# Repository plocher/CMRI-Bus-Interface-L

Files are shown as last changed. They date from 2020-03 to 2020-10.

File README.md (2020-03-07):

# CMRI-Bus-Interface-L
## License: Creative Commons Attribution-NonCommercial-ShareAlike

RS422/485 driver for CMRI-Net - large 3" Tyco rail size

Adapter board for interfacing with CMRI Bus traffic using MRCS ‘duino example code. Uses an optional onboard 555 to generate TX/RX enable based on processor I/O direction

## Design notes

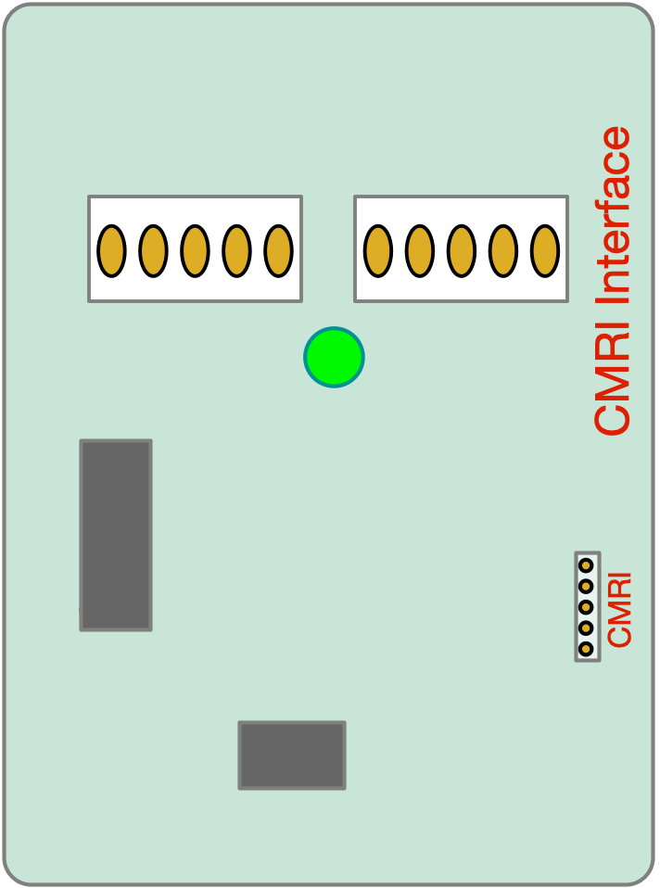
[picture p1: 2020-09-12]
CMRI-Bus-Interface-L-Graphic.png

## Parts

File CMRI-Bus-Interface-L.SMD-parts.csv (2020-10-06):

# name | smd? | value | package | component | x | y | Eagle-Angle | YX-Angle
C1 | SMD | 0.1uF | 0603-CAP | 0.1uf-0603-cap | 32.38 | 18.80 | 90.00 | -90.00
C2 | SMD | 0.01uF | 0603-CAP | 0.01uf-0603-cap | 29.21 | 10.16 | 270.00 | 90.00
C4 | SMD | 0.01uF | 0603-CAP | 0.01uf-0603-cap | 13.72 | 14.22 | 0.00 | 0.00
C5 | SMD | 0.01uF | 0603-CAP | 0.01uf-0603-cap | 19.43 | 10.16 | 270.00 | 90.00
D1 | SMD | BAV199 | SOT23 | bav199-sot23 | 15.24 | 10.16 | 90.00 | -90.00
R1-ALT | SMD | 12k | 0805-RES | 12k-0805-res | 32.51 | 10.16 | 270.00 | 90.00
R2 | SMD | 470 | 0805-RES | 470-0805-res | 38.10 | 45.09 | 90.00 | -90.00
TX | SMD | Y | 0603-LED | y-0603-led | 37.47 | 48.26 | 0.00 | 0.00
U1 | SMD | MAX3465CSD | SO14 | max3465csd-so14 | 13.97 | 20.32 | 90.00 | -90.00
U2 | SMD | NE555 | SO08 | ne555-so08 | 22.86 | 10.16 | 0.00 | 0.00

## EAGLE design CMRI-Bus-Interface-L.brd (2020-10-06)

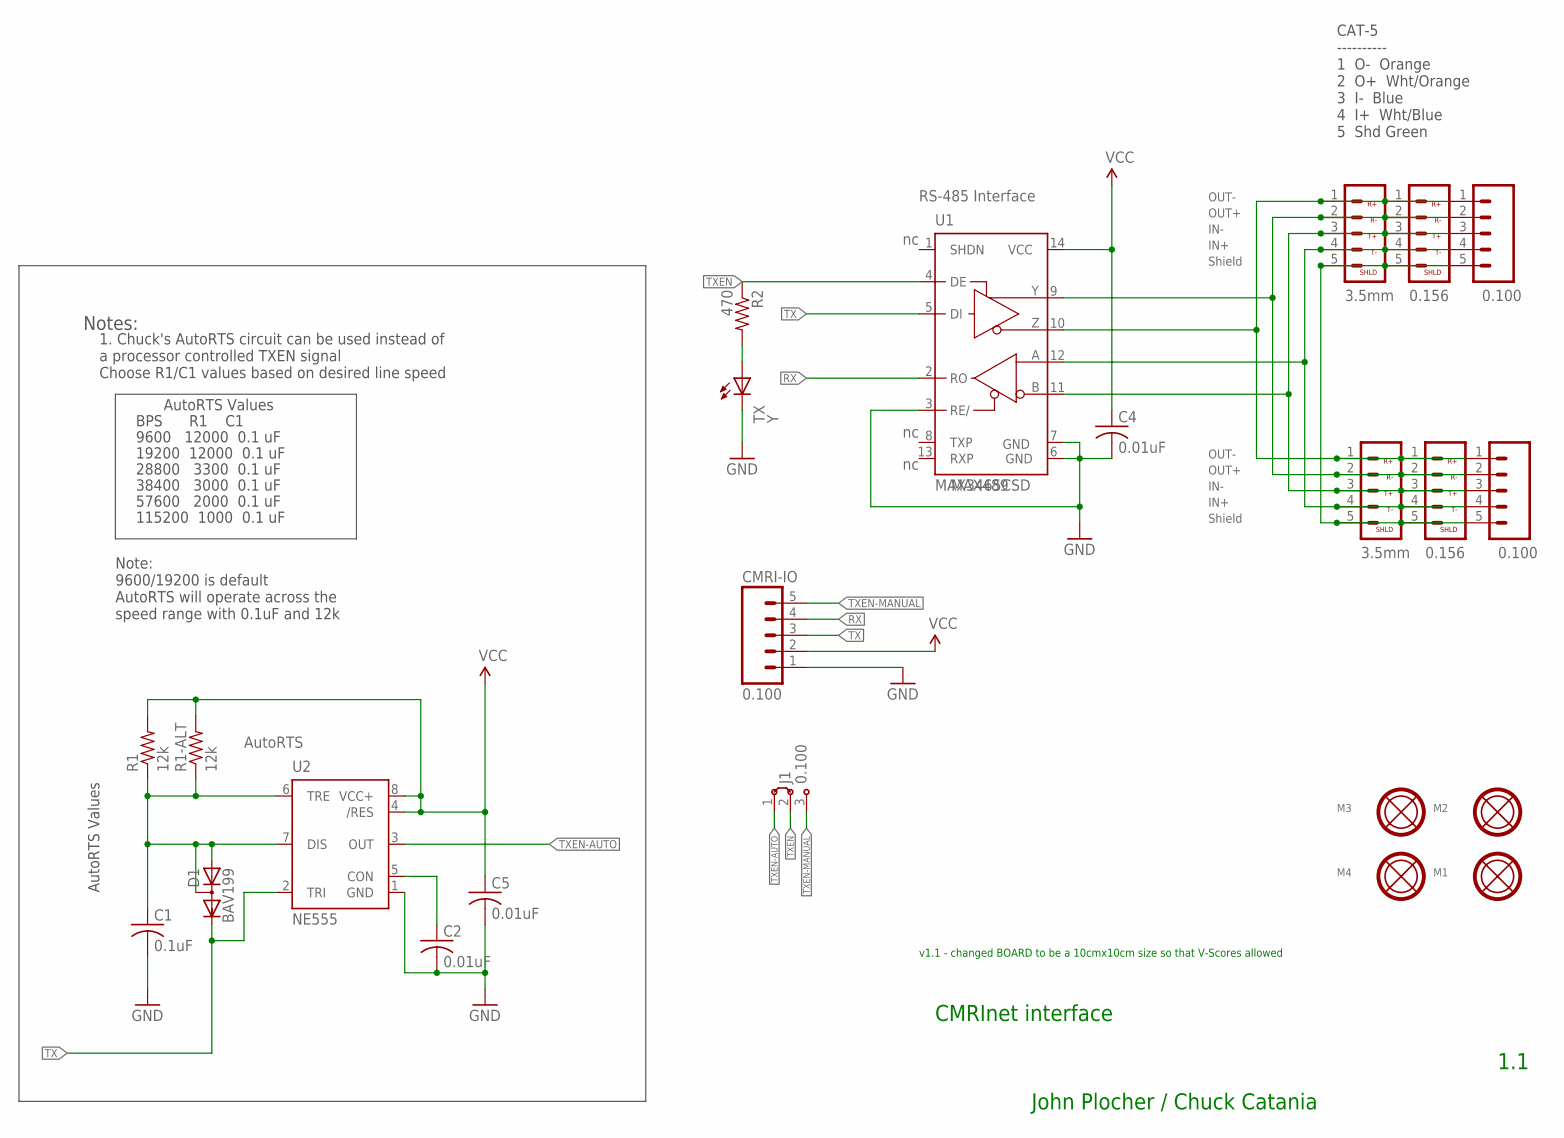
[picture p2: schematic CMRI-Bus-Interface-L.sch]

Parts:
C1: 0.1uF; 0603-CAP
C2, C4, C5: 0.01uF; 0603-CAP
CMRI-IO: 0.100; 1X05-CMRI-IO
CMRINET1, CMRINET2: 3.5mm; CMRINET-3.5MM
CMRINET3, CMRINET4: 0.156; KK-156-5
CON1, CON2: 0.100; 1X05_LOCK
D1: BAV199; SOT23
J1: 0.100; J3-254
M1, M2, M3, M4: MOUNTINGHOLE
R1: 12k; AXIAL-0.4-RES
R1-ALT: 12k; 0805-RES
R2: 470; 0805-RES
TX: Y; 0603-LED
U1: MAX3465CSD; SO14
U2: NE555; SO08

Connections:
GND: C1.2, C2.2, C4.2, C5.2, CMRI-IO.1, TX.C, U1.3 (RE/), U1.6 (GND), U1.7 (GND), U2.1 (GND)
IN+: CMRINET1.4, CMRINET2.4, CMRINET3.4, CMRINET4.4, CON1.4, CON2.4, U1.12 (A)
IN-: CMRINET1.3, CMRINET2.3, CMRINET3.3, CMRINET4.3, CON1.3, CON2.3, U1.11 (B)
unnamed: R2.2, TX.A
unnamed: C2.1, U2.5 (CON)
unnamed: C1.1, D1.1 (A), D1.3 (AC), R1.P$1 (1), R1-ALT.1, U2.6 (TRE), U2.7 (DIS)
OUT+: CMRINET1.2, CMRINET2.2, CMRINET3.2, CMRINET4.2, CON1.2, CON2.2, U1.9 (Y)
OUT-: CMRINET1.1, CMRINET2.1, CMRINET3.1, CMRINET4.1, CON1.1, CON2.1, U1.10 (Z)
RX: CMRI-IO.4, U1.2 (RO)
SHIELD: CMRINET1.5, CMRINET2.5, CMRINET3.5, CMRINET4.5, CON1.5, CON2.5
TX: CMRI-IO.3, D1.2 (C), U1.5 (DI), U2.2 (TRI)
TXEN: J1.2, R2.1, U1.4 (DE)
TXEN-AUTO: J1.1, U2.3 (OUT)
TXEN-MANUAL: CMRI-IO.5, J1.3
VCC: C4.1, C5.1, CMRI-IO.2, R1.P$2 (2), R1-ALT.2, U1.14 (VCC), U2.4 (/RES), U2.8 (VCC+)

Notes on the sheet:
MAX489
RS-485 Interface
Notes:
IN+
IN-
OUT+
OUT-
1. Chuck's AutoRTS circuit can be used instead of a processor controlled TXEN signal Choose R1/C1 values based on desired line speed
AutoRTS
AutoRTS Values
9600 12000 0.1 uF
19200 12000 0.1 uF
38400 3000 0.1 uF
57600 2000 0.1 uF
115200 1000 0.1 uF
BPS R1 C1
Shield
CAT-5 ---------- 1 O- Orange 2 O+ Wht/Orange 3 I- Blue 4 I+ Wht/Blue 5 Shd Green
28800 3300 0.1 uF
Note: 9600/19200 is default AutoRTS will operate across the speed range with 0.1uF and 12k
1.1
CMRInet interface
John Plocher / Chuck Catania
v1.1 - changed BOARD to be a 10cmx10cm size so that V-Scores allowed

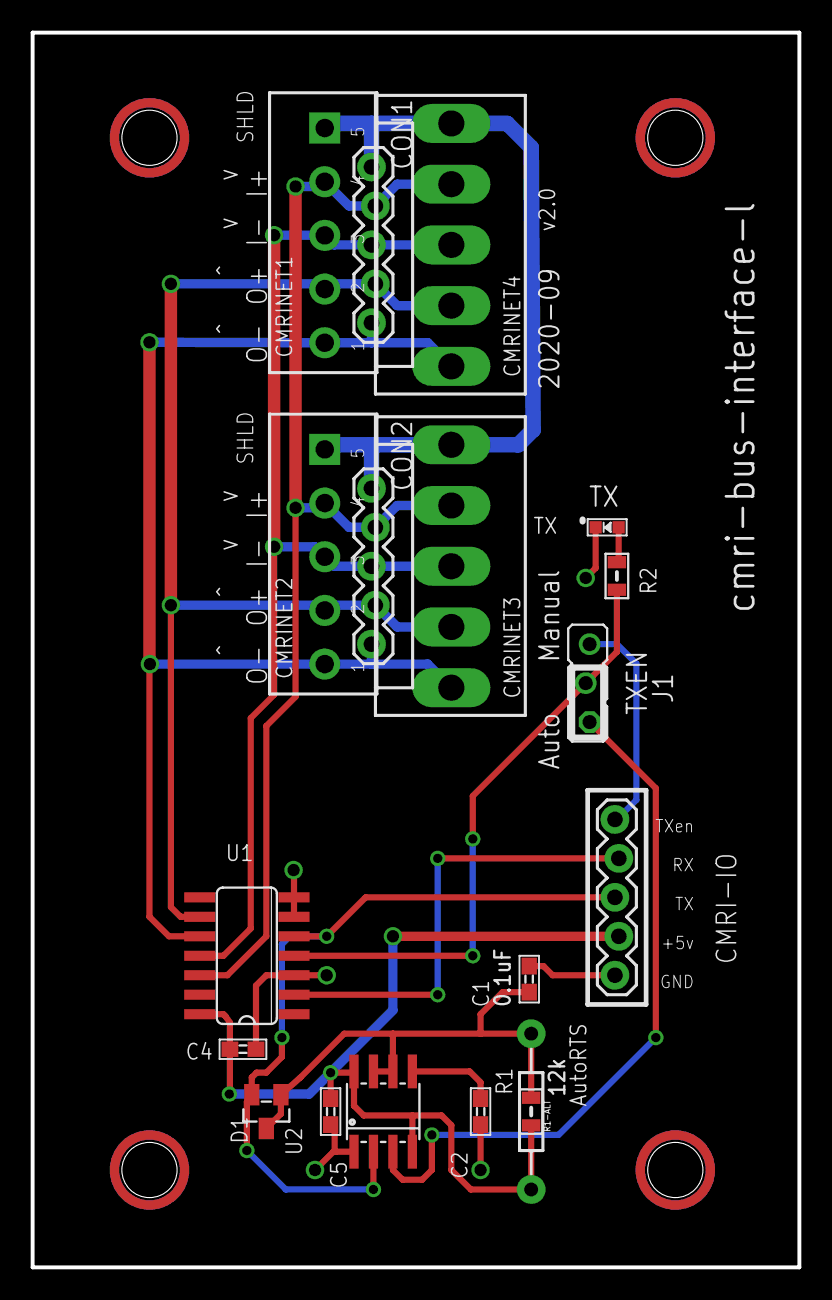
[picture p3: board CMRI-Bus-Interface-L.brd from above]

Board: 2 copper layers, 50.0 x 80.5 mm, 23 parts (0 on the bottom side), 15 nets.

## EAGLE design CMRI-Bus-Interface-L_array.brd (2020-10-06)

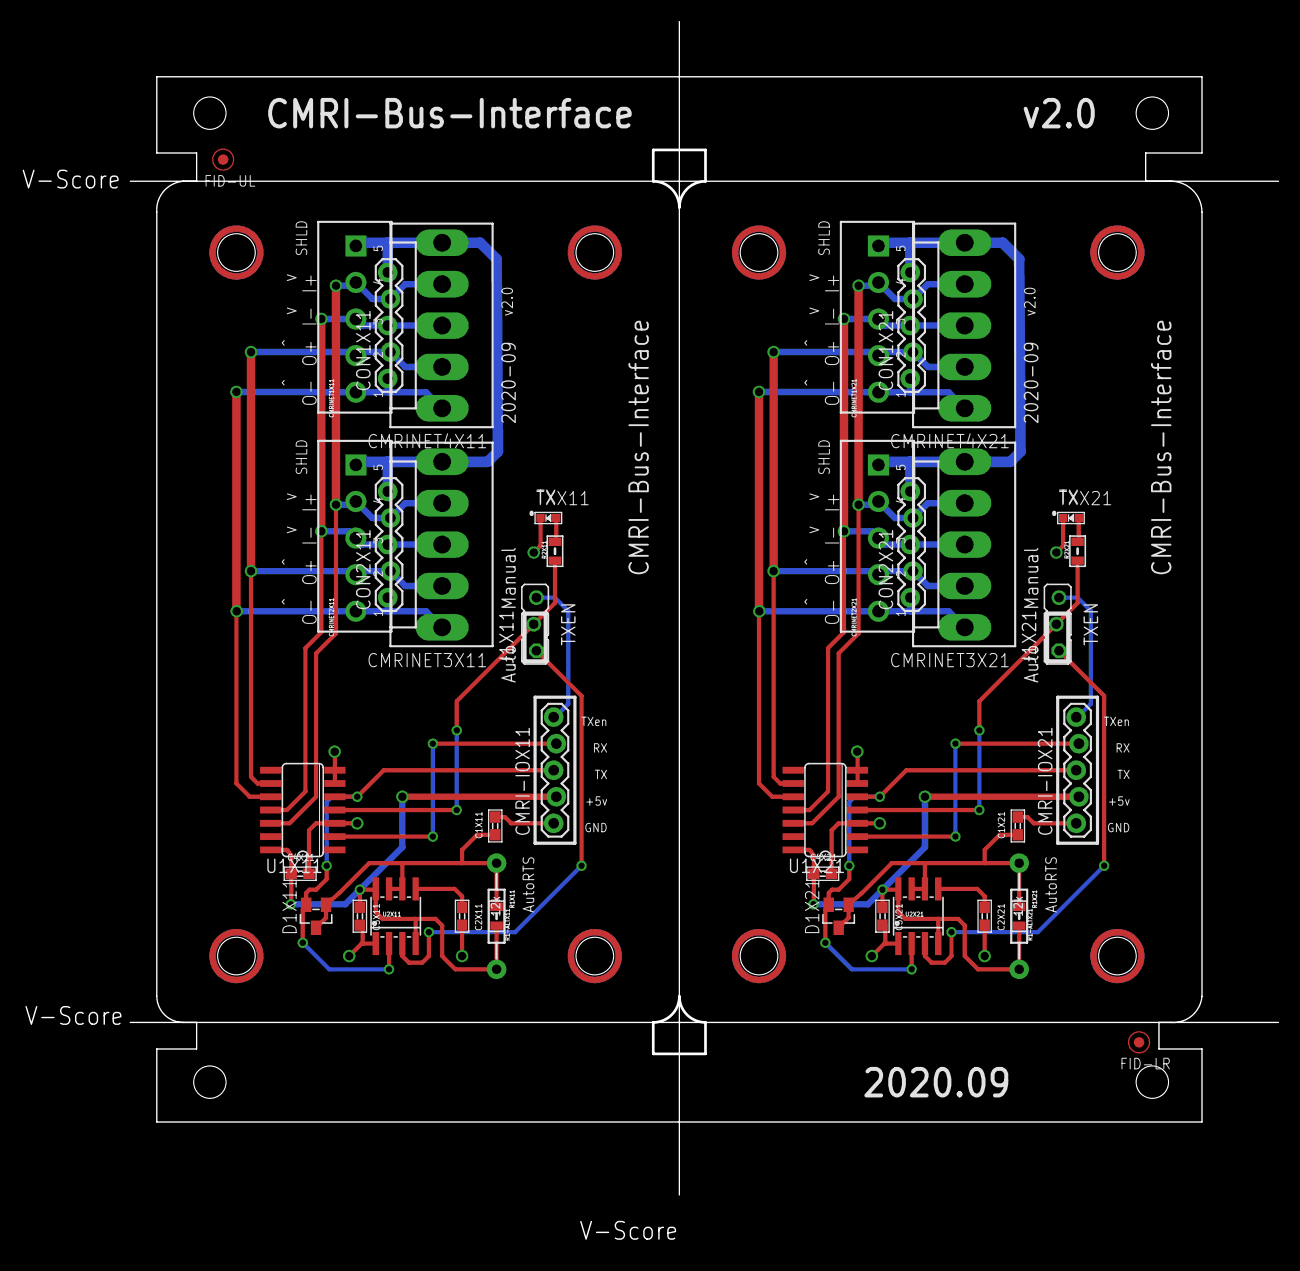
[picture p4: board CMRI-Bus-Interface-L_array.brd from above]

Board: 2 copper layers, 100.0 x 100.0 mm, 49 parts (0 on the bottom side), 30 nets.

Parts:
C1X11, C1X21: 0.1uF; 0603-CAP
C2X11, C2X21, C4X11, C4X21, C5X11, C5X21: .01uF; 0603-CAP
CMRI-IOX11, CMRI-IOX21: 0.100; 1X05-CMRI-IO
CMRINET1X11, CMRINET1X21, CMRINET2X11, CMRINET2X21: 3.5mm; CMRINET-3.5MM
CMRINET3X11, CMRINET3X21, CMRINET4X11, CMRINET4X21: 0.156; KK-156-5
CON1X11, CON1X21, CON2X11, CON2X21: 0.100; 1X05_LOCK
D1X11, D1X21: BAV199; SOT23
FID-LR: FIDUCIAL; FIDUCIAL_1MM
FID-UL: FIDUCIAL; FIDUCIAL_1MM
J1X11, J1X21: 0.100; J3-254
M1X11, M1X21, M2X11, M2X21, M3X11, M3X21, M4X11, M4X21: MOUNTINGHOLE
R1-ALTX11, R1-ALTX21: 12k; 0805-RES
R1X11, R1X21: 12k; AXIAL-0.4-RES
R2X11, R2X21: 470; 0805-RES
TXX11, TXX21: Y; 0603-LED
U1X11, U1X21: MAX3465CSD; SO14
U2X1: BOARD; BOARD-10X8X2-TEMPLATE
U2X11, U2X21: NE555; SO08

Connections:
GNDX11: C1X11.2, C2X11.2, C4X11.2, C5X11.2, CMRI-IOX11.1, TXX11.C, U1X11.3, U1X11.6, U1X11.7, U2X11.1
GNDX21: C1X21.2, C2X21.2, C4X21.2, C5X21.2, CMRI-IOX21.1, TXX21.C, U1X21.3, U1X21.6, U1X21.7, U2X21.1
IN+X11: CMRINET1X11.4, CMRINET2X11.4, CMRINET3X11.4, CMRINET4X11.4, CON1X11.4, CON2X11.4, U1X11.12
IN+X21: CMRINET1X21.4, CMRINET2X21.4, CMRINET3X21.4, CMRINET4X21.4, CON1X21.4, CON2X21.4, U1X21.12
IN-X11: CMRINET1X11.3, CMRINET2X11.3, CMRINET3X11.3, CMRINET4X11.3, CON1X11.3, CON2X11.3, U1X11.11
IN-X21: CMRINET1X21.3, CMRINET2X21.3, CMRINET3X21.3, CMRINET4X21.3, CON1X21.3, CON2X21.3, U1X21.11
unnamed: R2X11.2, TXX11.A
unnamed: R2X21.2, TXX21.A
unnamed: C2X11.1, U2X11.5
unnamed: C2X21.1, U2X21.5
unnamed: C1X11.1, D1X11.1, D1X11.3, R1-ALTX11.1, R1X11.P$1, U2X11.6, U2X11.7
unnamed: C1X21.1, D1X21.1, D1X21.3, R1-ALTX21.1, R1X21.P$1, U2X21.6, U2X21.7
OUT+X11: CMRINET1X11.2, CMRINET2X11.2, CMRINET3X11.2, CMRINET4X11.2, CON1X11.2, CON2X11.2, U1X11.9
OUT+X21: CMRINET1X21.2, CMRINET2X21.2, CMRINET3X21.2, CMRINET4X21.2, CON1X21.2, CON2X21.2, U1X21.9
OUT-X11: CMRINET1X11.1, CMRINET2X11.1, CMRINET3X11.1, CMRINET4X11.1, CON1X11.1, CON2X11.1, U1X11.10
OUT-X21: CMRINET1X21.1, CMRINET2X21.1, CMRINET3X21.1, CMRINET4X21.1, CON1X21.1, CON2X21.1, U1X21.10
RXX11: CMRI-IOX11.4, U1X11.2
RXX21: CMRI-IOX21.4, U1X21.2
SHIELDX11: CMRINET1X11.5, CMRINET2X11.5, CMRINET3X11.5, CMRINET4X11.5, CON1X11.5, CON2X11.5
SHIELDX21: CMRINET1X21.5, CMRINET2X21.5, CMRINET3X21.5, CMRINET4X21.5, CON1X21.5, CON2X21.5
TXEN-AUTOX11: J1X11.1, U2X11.3
TXEN-AUTOX21: J1X21.1, U2X21.3
TXEN-MANUALX11: CMRI-IOX11.5, J1X11.3
TXEN-MANUALX21: CMRI-IOX21.5, J1X21.3
TXENX11: J1X11.2, R2X11.1, U1X11.4
TXENX21: J1X21.2, R2X21.1, U1X21.4
TXX11: CMRI-IOX11.3, D1X11.2, U1X11.5, U2X11.2
TXX21: CMRI-IOX21.3, D1X21.2, U1X21.5, U2X21.2
VCCX11: C4X11.1, C5X11.1, CMRI-IOX11.2, R1-ALTX11.2, R1X11.P$2, U1X11.14, U2X11.4, U2X11.8
VCCX21: C4X21.1, C5X21.1, CMRI-IOX21.2, R1-ALTX21.2, R1X21.P$2, U1X21.14, U2X21.4, U2X21.8

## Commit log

2020-03-07 Initial version
    [CMRI-Bus-Interface-L.brd, CMRI-Bus-Interface-L.sch]
2020-04-25 v1.1 - changed BOARD to be a 10cmx10cm size so that V-Scores allowed
    [CMRI-Bus-Interface-L.brd, CMRI-Bus-Interface-L.sch]
2020-09-19 added missing component values
    [CMRI-Bus-Interface-L.SMD-parts.csv, CMRI-Bus-Interface-L.brd, CMRI-Bus-Interface-L.sch]
2020-09-21 SMT cost reduce
    [CMRI-Bus-Interface-L.SMD-parts.csv, CMRI-Bus-Interface-L.brd, CMRI-Bus-Interface-L.sch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]
2020-10-05 added values for connectors
    [CMRI-Bus-Interface-L.SMD-parts.csv, CMRI-Bus-Interface-L.brd, CMRI-Bus-Interface-L.sch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]
2020-10-06 normalized values
    [CMRI-Bus-Interface-L.brd, CMRI-Bus-Interface-L.sch, CMRI-Bus-Interface-L_array.brd]
